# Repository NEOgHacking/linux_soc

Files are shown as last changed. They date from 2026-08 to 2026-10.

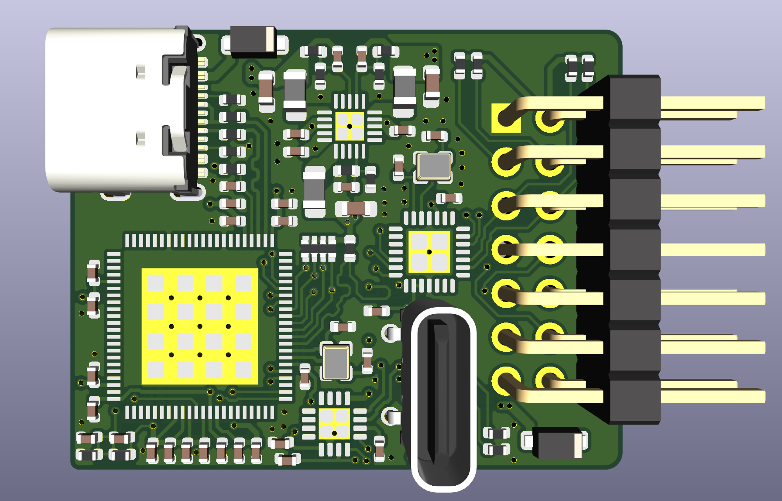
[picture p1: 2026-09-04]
Screenshot From 2026-09-04 17-12-16.png

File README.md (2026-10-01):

Screenshot From 2026-09-27 20-04-39

# linux_soc
Linux_soc is a very advanced linux capable module for the hackxpansion console, it consists of a F1C100s soc with integrated stacked ddr1 ram. It also contains a atmega 328p microcontroller, the same found on the arduino uno. It has its own usb ttl converter for programming. In total there are 2 usb ports one for the linux soc and one for the atmega. The pcb also contains a triple buck converter to meet the different requirements that are required by the linux soc

# Design
The linux soc module was designed in Kicad, i choose kicad because its opensource and its rich nature of features.

## Schematic







## PCB
The pcb consist of 4 layers for better power management and routing, it was otherwise also just impossible to do with all the different power rails.





## Case
The case was made in onshape. Here is the public link to access the document [link](https://cad.onshape.com/documents/23acd3255b900cc5b85fa1fc/w/7ef244823df79fb773706f50/e/0ac388d0a99e7c2b0060239b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) The case itself was made pretty complex also because of the complexity of the board, with no space for mouthing holes i had to resort to mounting it by clips.



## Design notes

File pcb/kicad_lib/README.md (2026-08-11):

# Hackxpansion KiCAD Lib

This library contatins the symbols for the male and female module connectors

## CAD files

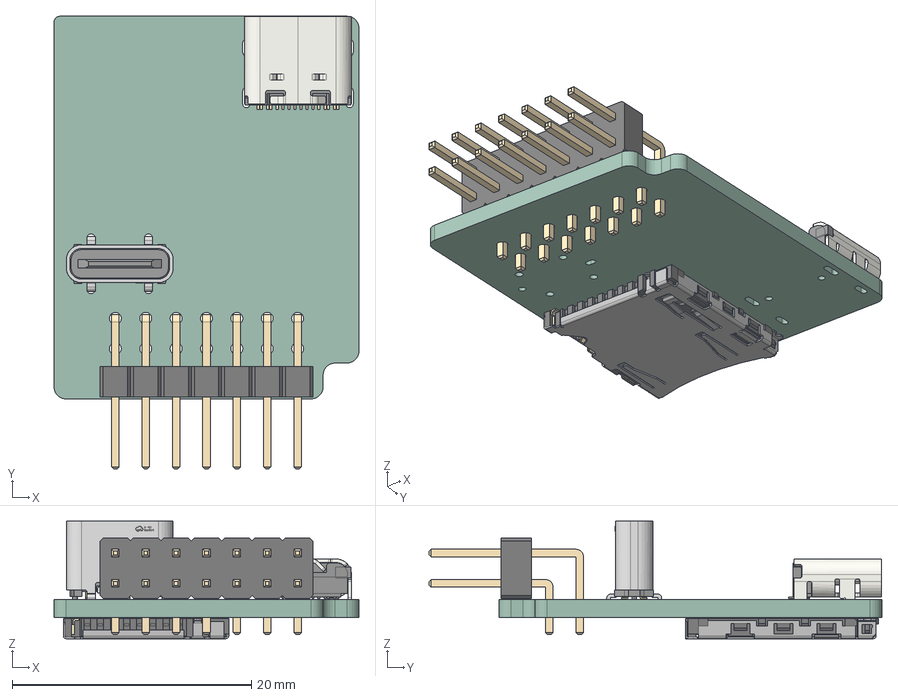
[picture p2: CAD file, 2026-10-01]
pcb/linux_soc.step
25.5 x 37.8 x 9.83 mm
USB-C-TH_GT-USB-7055BB
PinHeader_2x07_P254mm_Horizontal
USB_C_Receptacle_16P_TopMnt_Horizontal_GCT_USB4105-xx-A
microSD_HC_Hirose_DM3AT-SF-PEJM5
linux_soc-unsaved-export-cCa1nJ_PCB

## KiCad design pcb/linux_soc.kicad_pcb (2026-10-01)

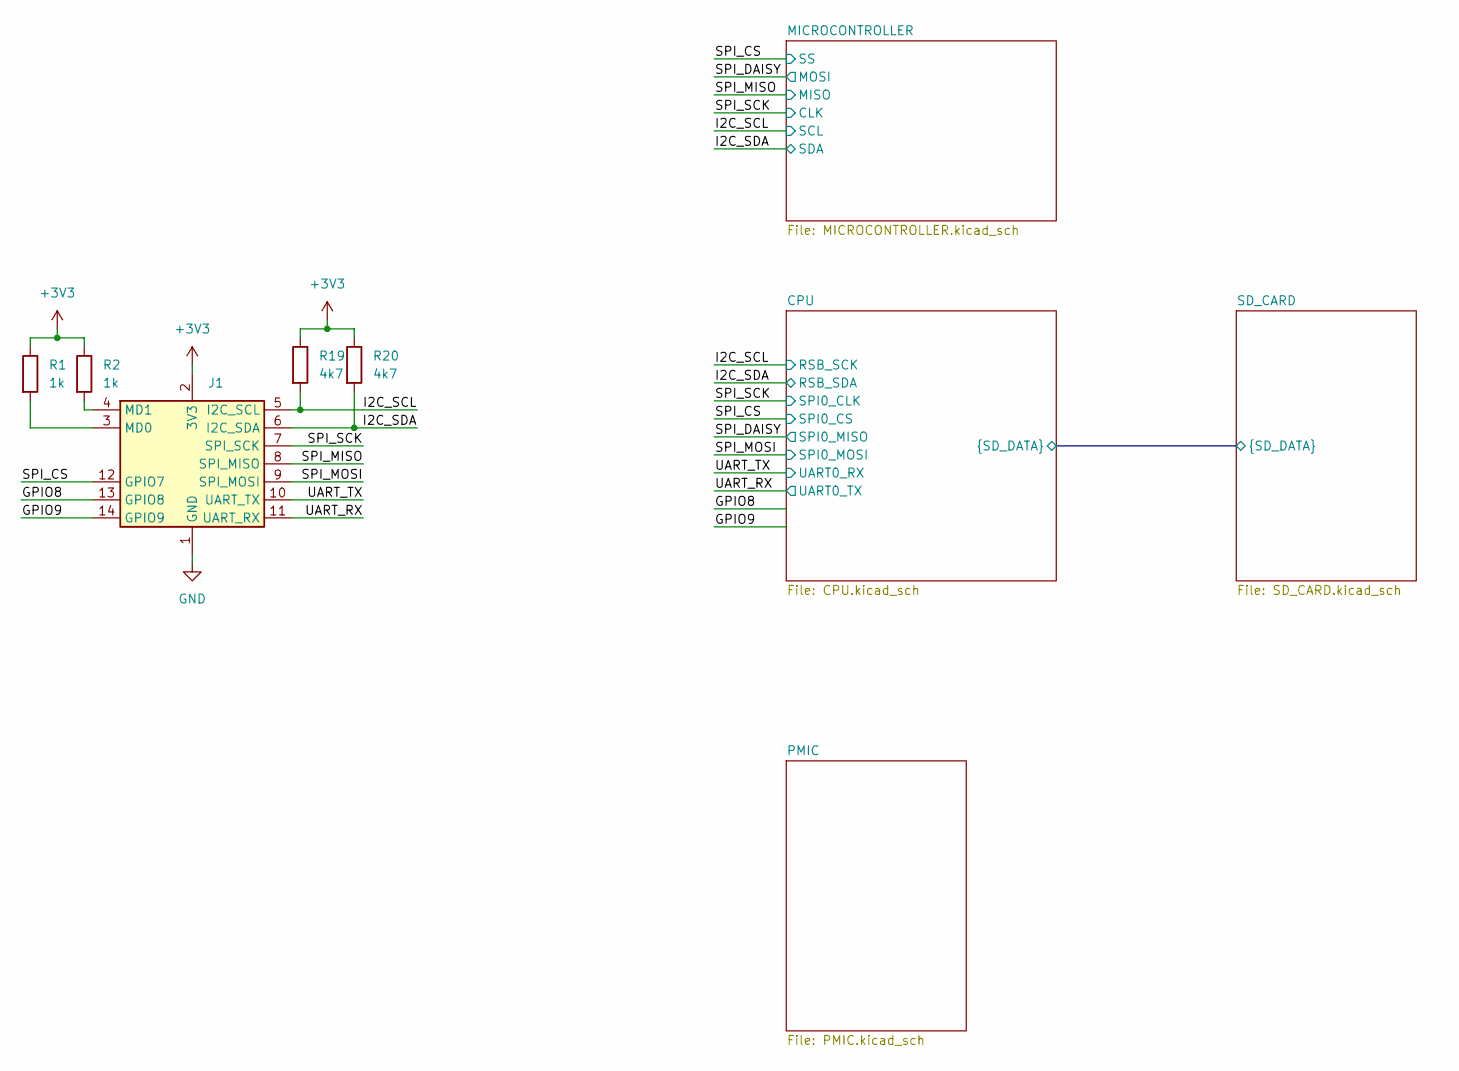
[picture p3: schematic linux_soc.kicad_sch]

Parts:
J1: PinHeader_2x07_P2.54mm_Horizontal; LCSC# C706888
R1, R2: 1k; R_0402_1005Metric
R19, R20: 4k7; R_0402_1005Metric

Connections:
+3V3: J1.2 (3V3), R1.1, R2.1, R19.1, R20.1; also elsewhere on the board
/GPIO8: J1.13 (GPIO8)
/GPIO9: J1.14 (GPIO9)
/I2C_SCL: J1.5 (I2C_SCL), R19.2; also elsewhere on the board
/I2C_SDA: J1.6 (I2C_SDA), R20.2; also elsewhere on the board
/SPI_CS: J1.12 (GPIO7); also elsewhere on the board
/SPI_MISO: J1.8 (SPI_MISO); also elsewhere on the board
/SPI_MOSI: J1.9 (SPI_MOSI); also elsewhere on the board
/SPI_SCK: J1.7 (SPI_SCK); also elsewhere on the board
/UART_RX: J1.11 (UART_RX); also elsewhere on the board
/UART_TX: J1.10 (UART_TX); also elsewhere on the board
GND: J1.1 (GND); also elsewhere on the board
unnamed: J1.3 (MD0), R1.2
unnamed: J1.4 (MD1), R2.2

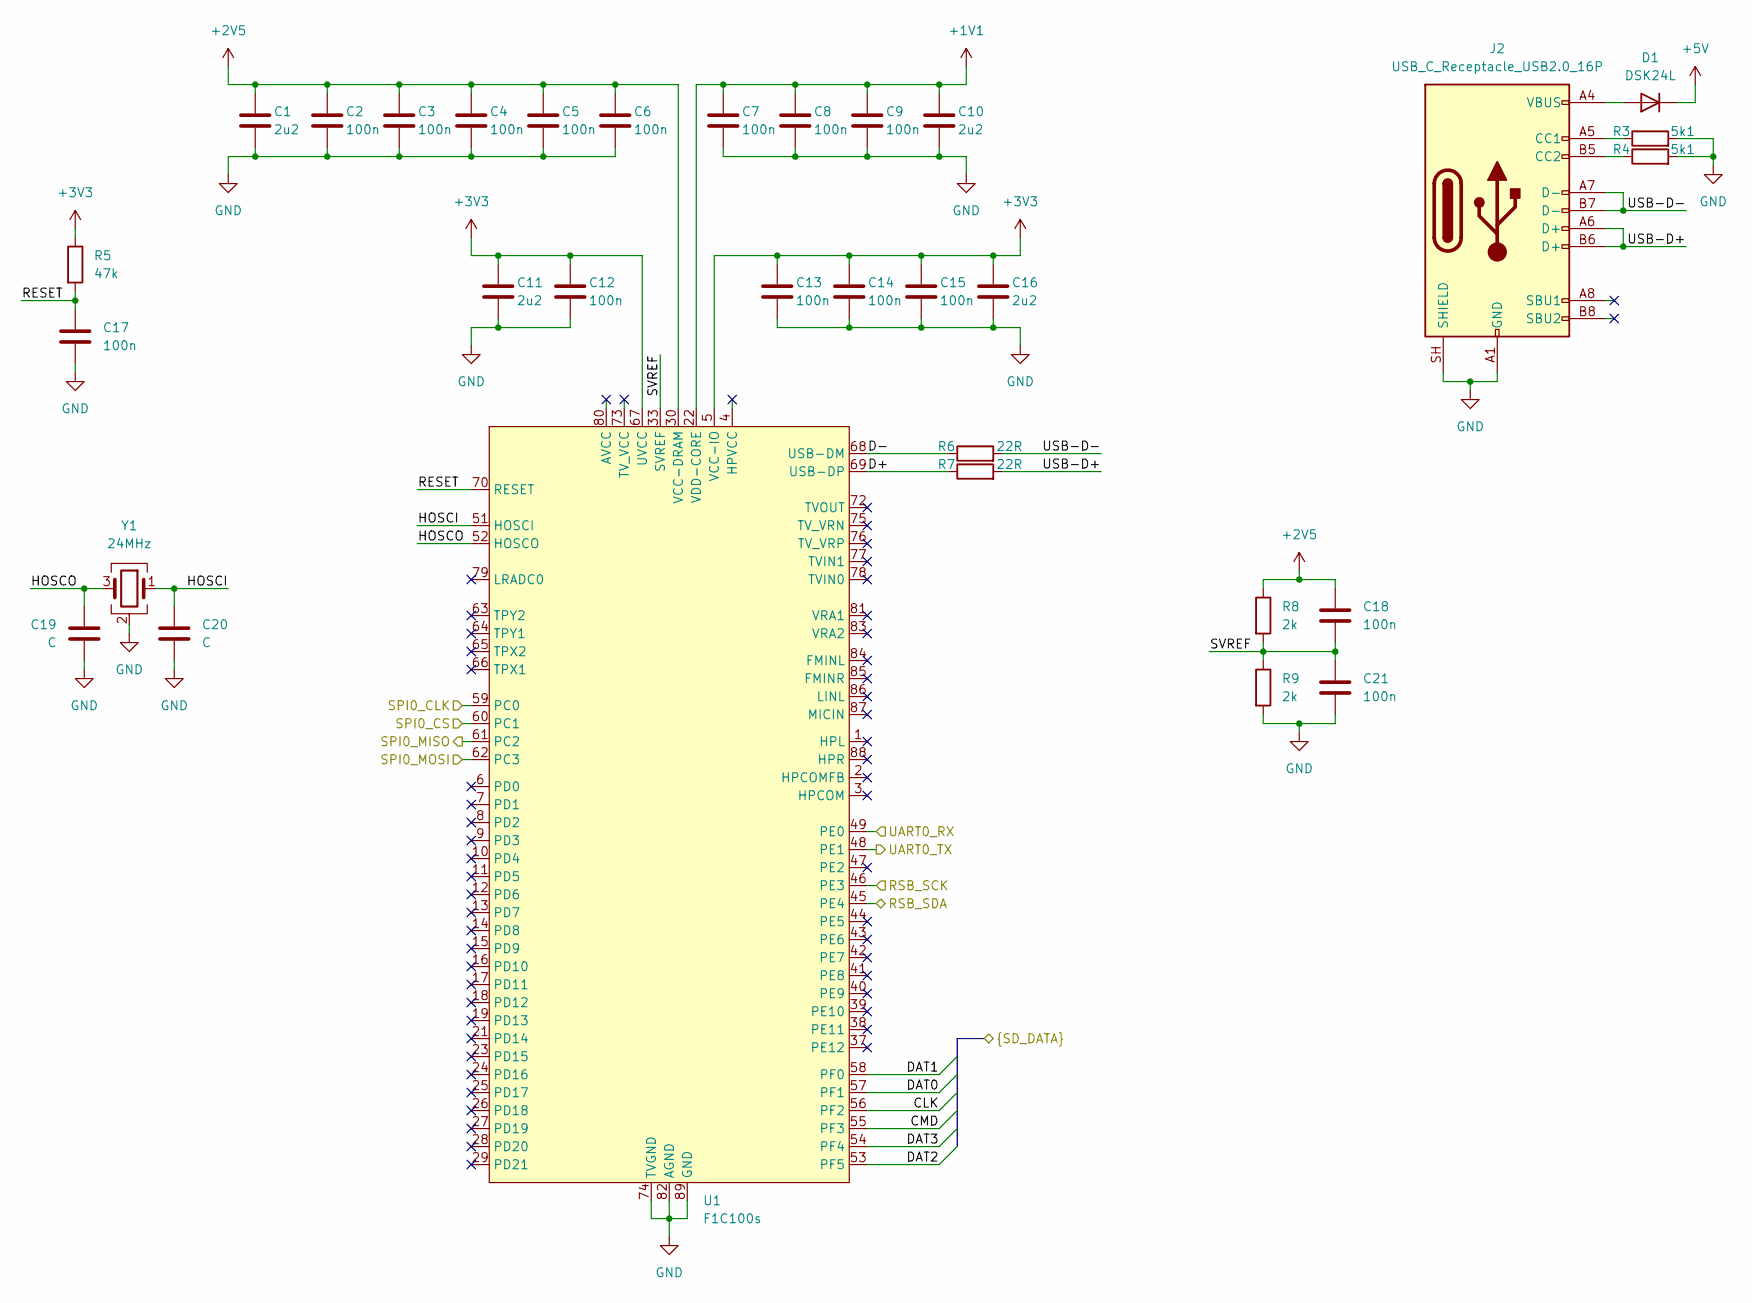
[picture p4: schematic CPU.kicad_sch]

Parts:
C1, C10, C11, C16: 2u2; C_0402_1005Metric
C2, C3, C4, C5, C6, C7, C8, C9, C12, C13, C14, C15, C17, C18, C21: 100n; C_0402_1005Metric
C19, C20: C; C_0402_1005Metric
D1: DSK24L; D_SOD-123F; LCSC# C19272974
J2: USB_C_Receptacle_USB2.0_16P; USB_C_Receptacle_GCT_USB4105-xx-A_16P_TopMnt_Horizontal; LCSC# C165948
R3, R4: 5k1; R_0402_1005Metric
R5: 47k; R_0402_1005Metric
R6, R7: 22R; R_0402_1005Metric
R8, R9: 2k; R_0402_1005Metric
U1: F1C100s; QFN-88_EP_10x10_Pitch0.4mm; LCSC# C1511928
Y1: 24MHz; Crystal_SMD_2016-4Pin_2.0x1.6mm

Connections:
+1V1: C7.1, C8.1, C9.1, C10.1, U1.22 (VDD-CORE), U1.35 (VDD-CORE), U1.71 (VDD-CORE); also elsewhere on the board
+2V5: C1.1, C2.1, C3.1, C4.1, C5.1, C6.1, C18.1, R8.1, U1.30 (VCC-DRAM), U1.31 (VCC-DRAM), U1.32 (VCC-DRAM), U1.34 (VCC-DRAM), U1.36 (VCC-DRAM); also elsewhere on the board
+3V3: C11.1, C12.1, C13.1, C14.1, C15.1, C16.1, R5.1, U1.5 (VCC-IO), U1.20 (VCC-IO), U1.50 (VCC-IO), U1.67 (UVCC); also elsewhere on the board
+5V: D1.1 (K); also elsewhere on the board
/CPU/CLK: U1.56 (PF2); also elsewhere on the board
/CPU/CMD: U1.55 (PF3); also elsewhere on the board
/CPU/D+: R7.1, U1.69 (USB-DP)
/CPU/D-: R6.1, U1.68 (USB-DM)
/CPU/DAT0: U1.57 (PF1); also elsewhere on the board
/CPU/DAT1: U1.58 (PF0); also elsewhere on the board
/CPU/DAT2: U1.53 (PF5); also elsewhere on the board
/CPU/DAT3: U1.54 (PF4); also elsewhere on the board
/CPU/HOSCI: C20.1, U1.51 (HOSCI), Y1.1
/CPU/HOSCO: C19.1, U1.52 (HOSCO), Y1.3
/CPU/RESET: C17.1, R5.2, U1.70 (RESET)
/CPU/SVREF: C18.2, C21.1, R8.2, R9.1, U1.33 (SVREF)
/CPU/USB-D+: J2.A6 (D+), J2.B6 (D+), R7.2
/CPU/USB-D-: J2.A7 (D-), J2.B7 (D-), R6.2
/I2C_SCL: U1.46 (PE3); also elsewhere on the board
/I2C_SDA: U1.45 (PE4); also elsewhere on the board
/SPI_CS: U1.60 (PC1); also elsewhere on the board
/SPI_DAISY: U1.61 (PC2); also elsewhere on the board
/SPI_MOSI: U1.62 (PC3); also elsewhere on the board
/SPI_SCK: U1.59 (PC0); also elsewhere on the board
/UART_RX: U1.48 (PE1); also elsewhere on the board
/UART_TX: U1.49 (PE0); also elsewhere on the board
GND: C1.2, C2.2, C3.2, C4.2, C5.2, C6.2, C7.2, C8.2, C9.2, C10.2, C11.2, C12.2, C13.2, C14.2, C15.2, C16.2, C17.2, C19.2, C20.2, C21.2, J2.A1 (GND), J2.A12 (GND), J2.B1 (GND), J2.B12 (GND), J2.SH (SHIELD), R3.2, R4.2, R9.2, U1.74 (TVGND), U1.82 (AGND), U1.89 (GND), Y1.2 (G), Y1.4 (G); also elsewhere on the board
unnamed: D1.2 (A), J2.A4 (VBUS), J2.A9 (VBUS), J2.B4 (VBUS), J2.B9 (VBUS)
unnamed: J2.A5 (CC1), R3.1
unnamed: J2.B5 (CC2), R4.1

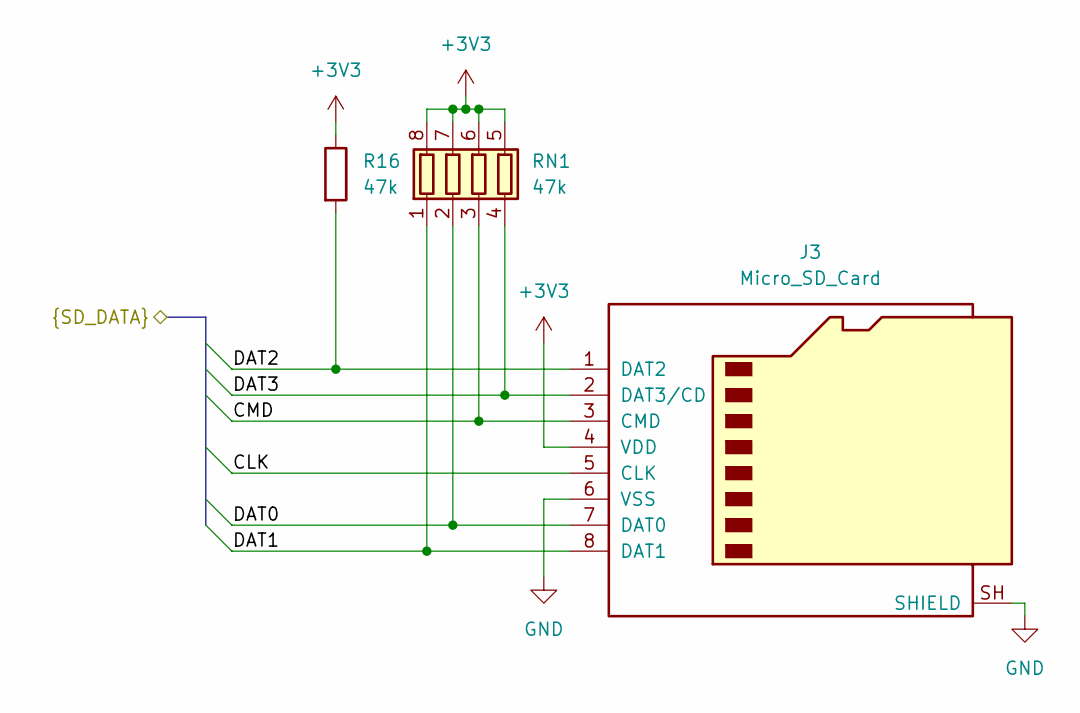
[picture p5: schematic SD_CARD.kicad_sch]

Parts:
J3: Micro_SD_Card; microSD_HC_Hirose_DM3AT-SF-PEJM5; LCSC# C114218
R16: 47k; R_0402_1005Metric
RN1: 47k; R_Array_Convex_4x0402; LCSC# C326859

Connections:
+3V3: J3.4 (VDD), R16.1, RN1.5 (R4.2), RN1.6 (R3.2), RN1.7 (R2.2), RN1.8 (R1.2); also elsewhere on the board
/CPU/CLK: J3.5 (CLK); also elsewhere on the board
/CPU/CMD: J3.3 (CMD), RN1.3 (R3.1); also elsewhere on the board
/CPU/DAT0: J3.7 (DAT0), RN1.2 (R2.1); also elsewhere on the board
/CPU/DAT1: J3.8 (DAT1), RN1.1 (R1.1); also elsewhere on the board
/CPU/DAT2: J3.1 (DAT2), R16.2; also elsewhere on the board
/CPU/DAT3: J3.2 (DAT3/CD), RN1.4 (R4.1); also elsewhere on the board
GND: J3.6 (VSS), J3.SH (SHIELD); also elsewhere on the board

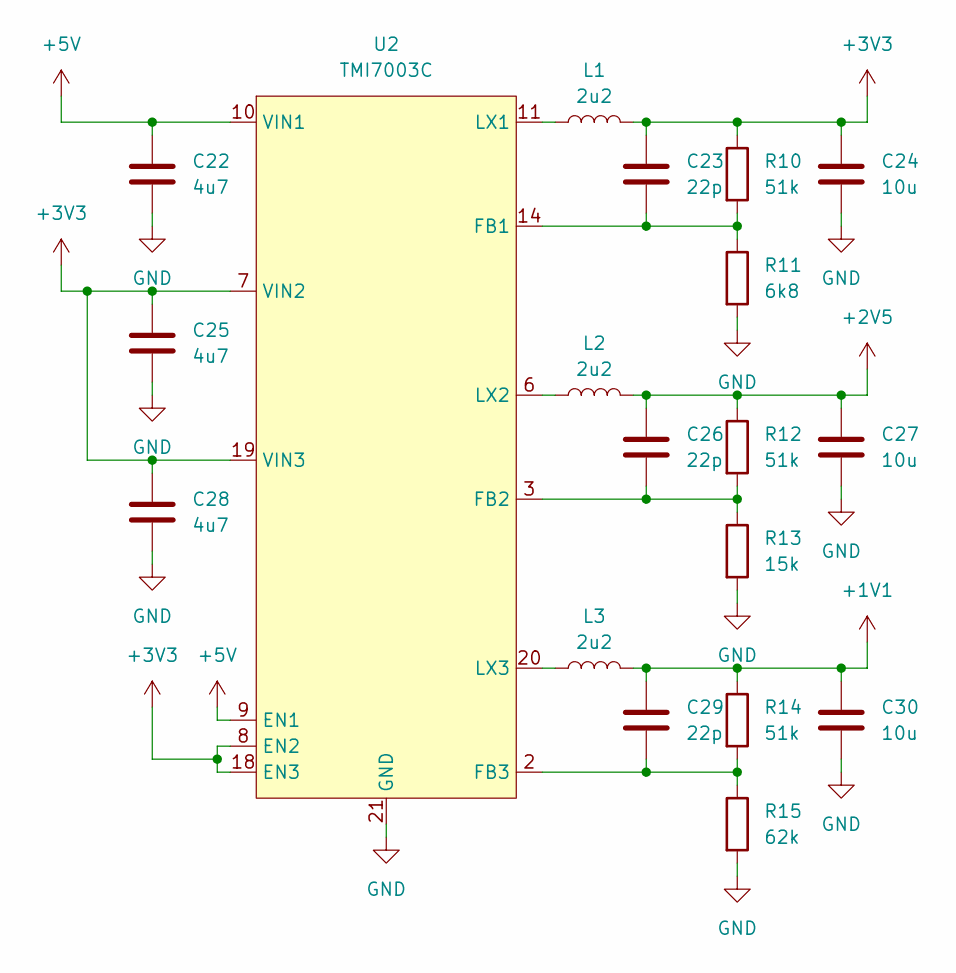
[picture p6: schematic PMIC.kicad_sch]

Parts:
C22, C25, C28: 4u7; C_0402_1005Metric
C23, C26, C29: 22p; C_0402_1005Metric
C24, C27, C30: 10u; C_0603_1608Metric
L1, L2, L3: 2u2; L_0805_2012Metric; LCSC# C22471111
R10, R12, R14: 51k; R_0402_1005Metric
R11: 6k8; R_0402_1005Metric
R13: 15k; R_0402_1005Metric
R15: 62k; R_0402_1005Metric
U2: TMI7003C; QFN-20-1EP_3x3mm_P0.4mm_EP1.65x1.65mm; LCSC# C840566

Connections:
+1V1: C29.1, C30.1, L3.2, R14.1; also elsewhere on the board
+2V5: C26.1, C27.1, L2.2, R12.1; also elsewhere on the board
+3V3: C23.1, C24.1, C25.1, C28.1, L1.2, R10.1, U2.7 (VIN2), U2.8 (EN2), U2.18 (EN3), U2.19 (VIN3); also elsewhere on the board
+5V: C22.1, U2.9 (EN1), U2.10 (VIN1); also elsewhere on the board
GND: C22.2, C24.2, C25.2, C27.2, C28.2, C30.2, R11.2, R13.2, R15.2, U2.21 (GND); also elsewhere on the board
unnamed: C23.2, R10.2, R11.1, U2.14 (FB1)
unnamed: C26.2, R12.2, R13.1, U2.3 (FB2)
unnamed: C29.2, R14.2, R15.1, U2.2 (FB3)
unnamed: L1.1, U2.11 (LX1)
unnamed: L2.1, U2.6 (LX2)
unnamed: L3.1, U2.20 (LX3)

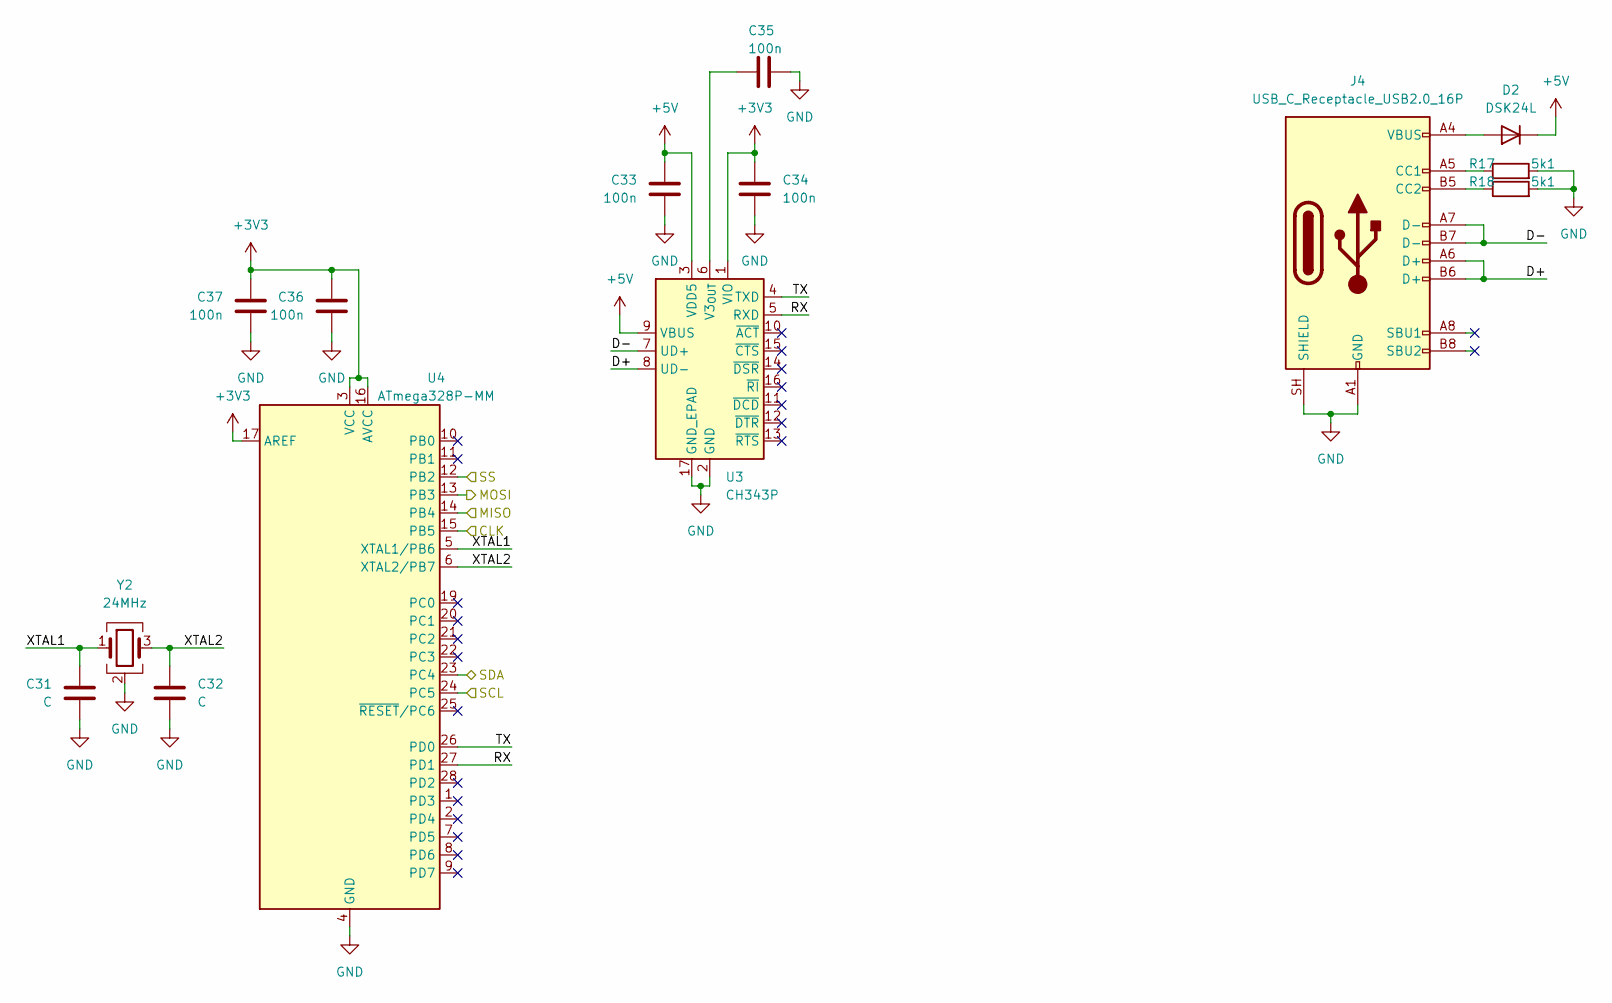
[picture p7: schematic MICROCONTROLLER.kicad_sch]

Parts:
C31, C32: C; C_0402_1005Metric
C33, C34, C35, C36, C37: 100n; C_0402_1005Metric
D2: DSK24L; D_SOD-123F; LCSC# C19272974
J4: USB_C_Receptacle_USB2.0_16P; USB_C_Receptacle_Vertical; LCSC# C165948
R17, R18: 5k1; R_0402_1005Metric
U3: CH343P; WCH_QFN-16-1EP_3x3mm_P0.5mm_EP1.8x1.8mm
U4: ATmega328P-MM; QFN-28-1EP_4x4mm_P0.45mm_EP2.4x2.4mm
Y2: 24MHz; Crystal_SMD_2016-4Pin_2.0x1.6mm

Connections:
+3V3: C34.1, C36.1, C37.1, U3.1 (VIO), U4.3 (VCC), U4.16 (AVCC), U4.17 (AREF); also elsewhere on the board
+5V: C33.1, D2.1 (K), U3.3 (VDD5), U3.9 (VBUS); also elsewhere on the board
/I2C_SCL: U4.24 (PC5); also elsewhere on the board
/I2C_SDA: U4.23 (PC4); also elsewhere on the board
/MICROCONTROLLER/D+: J4.A6 (D+), J4.B6 (D+), U3.8 (UD-)
/MICROCONTROLLER/D-: J4.A7 (D-), J4.B7 (D-), U3.7 (UD+)
/MICROCONTROLLER/RX: U3.5 (RXD), U4.27 (PD1)
/MICROCONTROLLER/TX: U3.4 (TXD), U4.26 (PD0)
/MICROCONTROLLER/XTAL1: C31.1, U4.5 (XTAL1/PB6), Y2.1
/MICROCONTROLLER/XTAL2: C32.1, U4.6 (XTAL2/PB7), Y2.3
/SPI_CS: U4.12 (PB2); also elsewhere on the board
/SPI_DAISY: U4.13 (PB3); also elsewhere on the board
/SPI_MISO: U4.14 (PB4); also elsewhere on the board
/SPI_SCK: U4.15 (PB5); also elsewhere on the board
GND: C31.2, C32.2, C33.2, C34.2, C35.1, C36.2, C37.2, J4.A1 (GND), J4.A12 (GND), J4.B1 (GND), J4.B12 (GND), J4.SH (SHIELD), R17.2, R18.2, U3.2 (GND), U3.17 (GND_EPAD), U4.4 (GND), U4.18 (GND), U4.29 (GND), Y2.2 (G), Y2.4 (G); also elsewhere on the board
unnamed: D2.2 (A), J4.A4 (VBUS), J4.A9 (VBUS), J4.B4 (VBUS), J4.B9 (VBUS)
unnamed: J4.A5 (CC1), R17.1
unnamed: J4.B5 (CC2), R18.1
unnamed: C35.2, U3.6 (V3_{OUT})

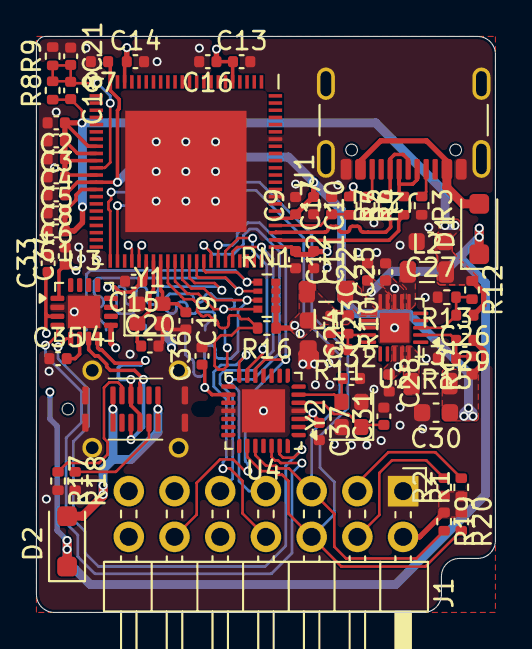
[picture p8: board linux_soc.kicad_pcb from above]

Board: 4 copper layers, 25.5 x 32.0 mm, 73 parts (1 on the bottom side), 49 nets.

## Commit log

2026-08-11 Added all the stuff
    [CPU.kicad_sch, MICROCONTROLLER.kicad_sch, PMIC.kicad_sch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]
2026-08-31 Completed PCB
    [MICROCONTROLLER.kicad_sch, linux_soc.kicad_pcb, linux_soc.kicad_sch]
2026-10-01 Fixed some things
    [linux_soc.kicad_pcb, linux_soc.step]
2026-10-01 Update README with linux_soc module details
    Added detailed information about the linux_soc module, including design, schematic, PCB details, and case design.
2026-10-11 Added bom and fixed PCB with LCSC numbers
2026-10-11 Added BOM to readme
